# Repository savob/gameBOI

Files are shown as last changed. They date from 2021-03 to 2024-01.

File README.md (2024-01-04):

# gameBOI

My first personal circuit board project which I took on sort of like a hackathon to get done fast so I could show potential employers in the summer of 2019. Designed, ordered, assembled, programmed and debugged in the space of two weeks! Unfotunately I didn't get to show it off much given my limited number of interviews, but still proud of it.

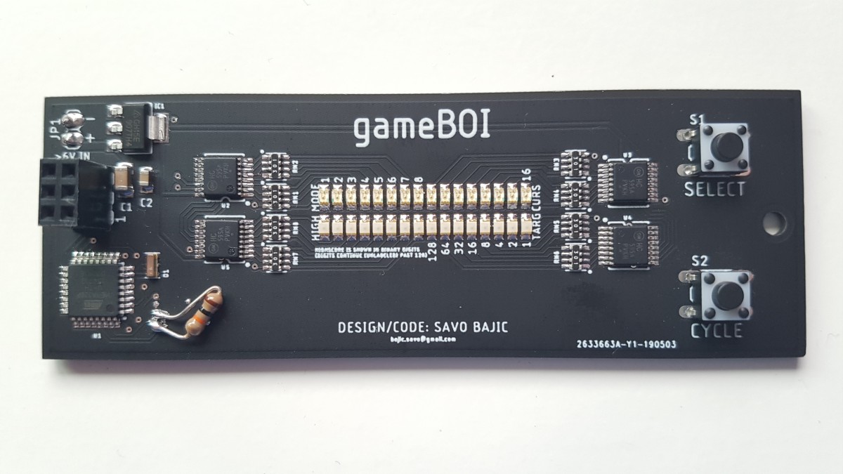
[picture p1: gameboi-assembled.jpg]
Assembled gameBOI board


*I initially forgot to buy one SMD resistor, so had to use a through-hole one.* 

## Hardware

The design is pretty simple looking back, basically the heart of an Arduino Nano with four shift registers daisy-chained to control the LEDs on board. There are two buttons for user input and two rows of 16 LEDs each resulting in the games and UI/UX being pretty simplistic. Power was supplied through a 9V battery that hung off the board going through a linear regulator.

I made two versions of the design, and commited to having the second built and assembled.

## Firmware

By replicating the heart of an Arduino Nano on the board, I could program it just like one through the Arduino IDE. One however was that instead of using a USB-UART interface and the Optiboot bootloader to program the chip, I used the AVR-ISP interface using an Arduino Uno as an ISP.

My code organization was pretty simple and I tried to make it easily scalable. I decided early on that I would make a seperate file for each sort of "stage" the user was in, so `mainmenu` and one for each different game (e.g. `stacker`), as well as one for all the shared functions like updating the screen so they could be maintained easier. *I now realize that what I had accidentally created was a Finite State Machine (FSM), and a project specific library.*

## Software Used

The board was designed in EAGLE (based on release dates, probably v9.4.0). Code was written in the Arduino IDE v1.8.9.

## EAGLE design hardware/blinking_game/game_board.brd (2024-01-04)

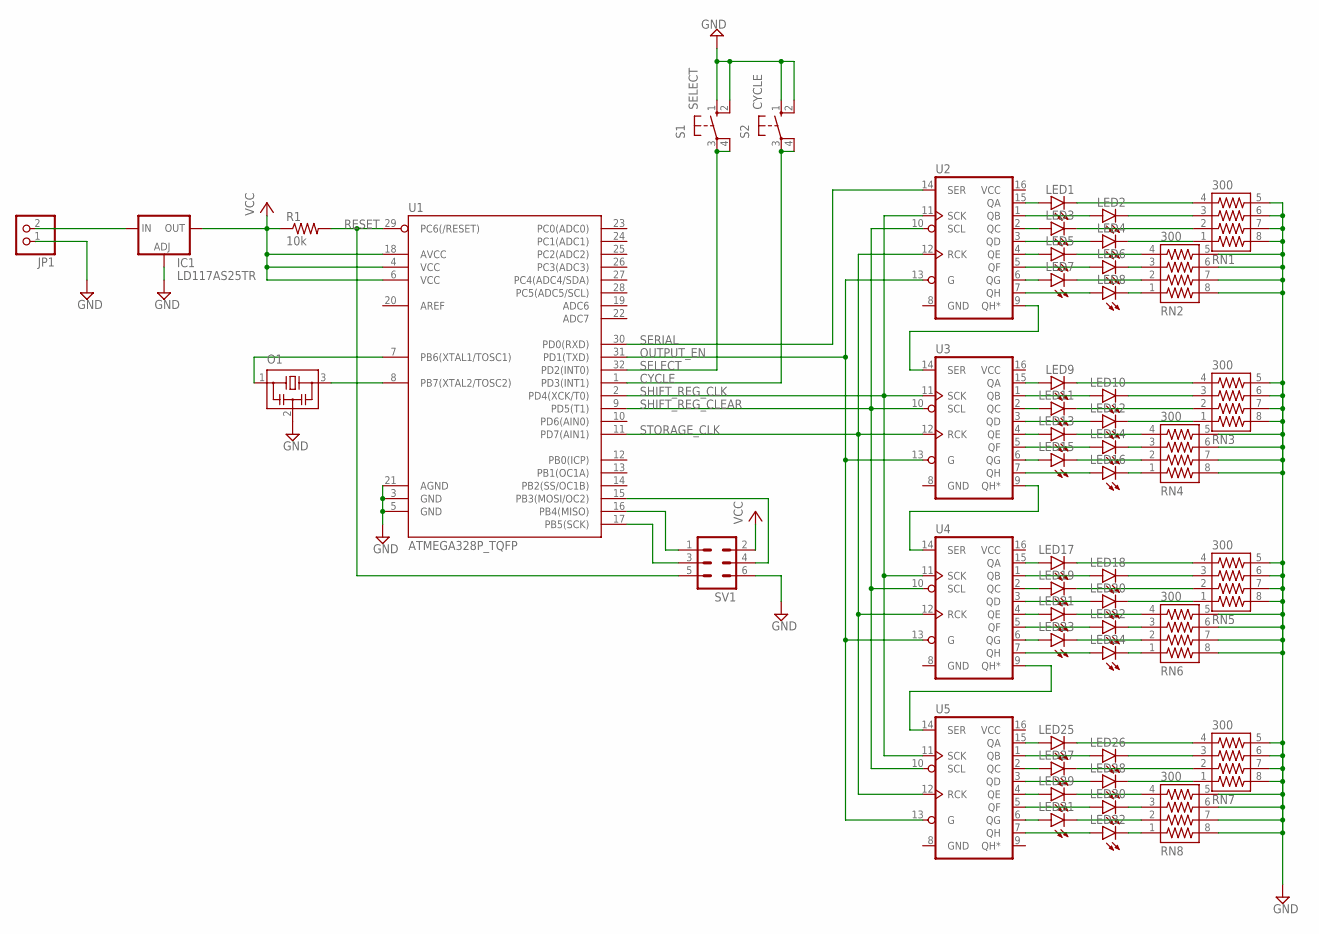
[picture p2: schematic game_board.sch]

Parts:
IC1: LD117AS25TR; SOT223
JP1: PINHD-1X2; 1X02
LED1, LED2, LED3, LED4, LED5, LED6, LED7, LED8, LED9, LED10, LED11, LED12, LED13, LED14, LED15, LED16, LED17, LED18, LED19, LED20, LED21, LED22, LED23, LED24, LED25, LED26, LED27, LED28, LED29, LED30, LED31, LED32: LEDSML0805; SML0805
O1: CSTNE16M0V530000R0; CSTCR6M
R1: 10k; R0603
RN1, RN2, RN3, RN4, RN5, RN6, RN7, RN8: 300; RESCAXS80P320X250X60-8
S1: SELECT; B3F-10XX
S2: CYCLE; B3F-10XX
SV1: MA03-2
U1: ATMEGA328P_TQFP; TQFP32-08
U2, U3, U4, U5: 74595; TSSOP16

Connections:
CYCLE: S2.3, S2.4 (P1), U1.1 (PD3(INT1))
GND: IC1.1 (ADJ), JP1.1, O1.2, RN1.5, RN1.6, RN1.7, RN1.8, RN2.5, RN2.6, RN2.7, RN2.8, RN3.5, RN3.6, RN3.7, RN3.8, RN4.5, RN4.6, RN4.7, RN4.8, RN5.5, RN5.6, RN5.7, RN5.8, RN6.5, RN6.6, RN6.7, RN6.8, RN7.5, RN7.6, RN7.7, RN7.8, RN8.5, RN8.6, RN8.7, RN8.8, S1.1 (S), S1.2 (S1), S2.1 (S), S2.2 (S1), SV1.6, U1.3 (GND), U1.5 (GND), U1.21 (AGND), U2.8 (GND), U3.8 (GND), U4.8 (GND), U5.8 (GND)
MISO: SV1.1, U1.16 (PB4(MISO))
MOSI: SV1.4, U1.15 (PB3(MOSI/OC2))
unnamed: O1.1, U1.7 (PB6(XTAL1/TOSC1))
unnamed: O1.3, U1.8 (PB7(XTAL2/TOSC2))
unnamed: LED17.A, U4.15 (QA)
unnamed: LED18.A, U4.1 (QB)
unnamed: LED17.C, RN5.4
unnamed: LED18.C, RN5.3
unnamed: U3.9 (QH*), U4.14 (SER)
unnamed: U2.9 (QH*), U3.14 (SER)
unnamed: U4.9 (QH*), U5.14 (SER)
unnamed: LED1.A, U2.15 (QA)
unnamed: LED2.A, U2.1 (QB)
unnamed: LED1.C, RN1.4
unnamed: LED2.C, RN1.3
unnamed: LED3.A, U2.2 (QC)
unnamed: LED3.C, RN1.2
unnamed: LED4.C, RN1.1
unnamed: LED4.A, U2.3 (QD)
unnamed: LED5.A, U2.4 (QE)
unnamed: LED6.A, U2.5 (QF)
unnamed: LED5.C, RN2.4
unnamed: LED6.C, RN2.3
unnamed: LED7.C, RN2.2
unnamed: LED7.A, U2.6 (QG)
unnamed: LED8.A, U2.7 (QH)
unnamed: LED8.C, RN2.1
unnamed: LED9.A, U3.15 (QA)
unnamed: LED10.A, U3.1 (QB)
unnamed: LED9.C, RN3.4
unnamed: LED10.C, RN3.3
unnamed: LED11.A, U3.2 (QC)
unnamed: LED11.C, RN3.2
unnamed: LED12.C, RN3.1
unnamed: LED12.A, U3.3 (QD)
unnamed: LED13.A, U3.4 (QE)
unnamed: LED14.A, U3.5 (QF)
unnamed: LED13.C, RN4.4
unnamed: LED14.C, RN4.3
unnamed: LED15.C, RN4.2
unnamed: LED15.A, U3.6 (QG)
unnamed: LED16.A, U3.7 (QH)
unnamed: LED16.C, RN4.1
unnamed: LED19.A, U4.2 (QC)
unnamed: LED19.C, RN5.2
unnamed: LED20.C, RN5.1
unnamed: LED20.A, U4.3 (QD)
unnamed: LED21.A, U4.4 (QE)
unnamed: LED22.A, U4.5 (QF)
unnamed: LED21.C, RN6.4
unnamed: LED22.C, RN6.3
unnamed: LED23.C, RN6.2
unnamed: LED23.A, U4.6 (QG)
unnamed: LED24.A, U4.7 (QH)
unnamed: LED24.C, RN6.1
unnamed: LED25.A, U5.15 (QA)
unnamed: LED26.A, U5.1 (QB)
unnamed: LED25.C, RN7.4
unnamed: LED26.C, RN7.3
unnamed: LED27.A, U5.2 (QC)
unnamed: LED27.C, RN7.2
unnamed: LED28.C, RN7.1
unnamed: LED28.A, U5.3 (QD)
unnamed: LED29.A, U5.4 (QE)
unnamed: LED30.A, U5.5 (QF)
unnamed: LED29.C, RN8.4
unnamed: LED30.C, RN8.3
unnamed: LED31.C, RN8.2
unnamed: LED31.A, U5.6 (QG)
unnamed: LED32.A, U5.7 (QH)
unnamed: LED32.C, RN8.1
unnamed: IC1.3 (IN), JP1.2
OUTPUT_EN: U1.31 (PD1(TXD)), U2.13 (G), U3.13 (G), U4.13 (G), U5.13 (G)
RESET: R1.2, SV1.5, U1.29 (PC6(/RESET))
SCK: SV1.3, U1.17 (PB5(SCK))
SELECT: S1.3, S1.4 (P1), U1.32 (PD2(INT0))
SERIAL: U1.30 (PD0(RXD)), U2.14 (SER)
SHIFT_REG_CLEAR: U1.9 (PD5(T1)), U2.10 (SCL), U3.10 (SCL), U4.10 (SCL), U5.10 (SCL)
SHIFT_REG_CLK: U1.2 (PD4(XCK/T0)), U2.11 (SCK), U3.11 (SCK), U4.11 (SCK), U5.11 (SCK)
STORAGE_CLK: U1.11 (PD7(AIN1)), U2.12 (RCK), U3.12 (RCK), U4.12 (RCK), U5.12 (RCK)
VCC: IC1.4 (OUT), R1.1, SV1.2, U1.4 (VCC), U1.6 (VCC), U1.18 (AVCC), U2.16 (VCC), U3.16 (VCC), U4.16 (VCC), U5.16 (VCC)

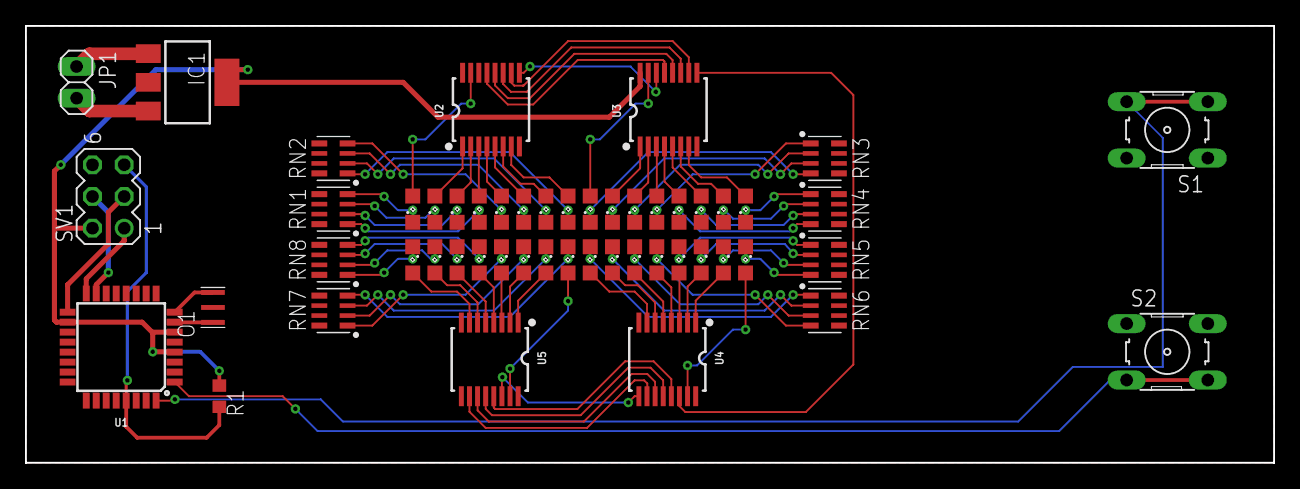
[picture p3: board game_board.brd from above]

Board: 2 copper layers, 100.0 x 35.0 mm, 52 parts (0 on the bottom side), 83 nets.

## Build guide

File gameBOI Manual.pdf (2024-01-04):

# gameBOI Manual

By: Savo Bajic, of course

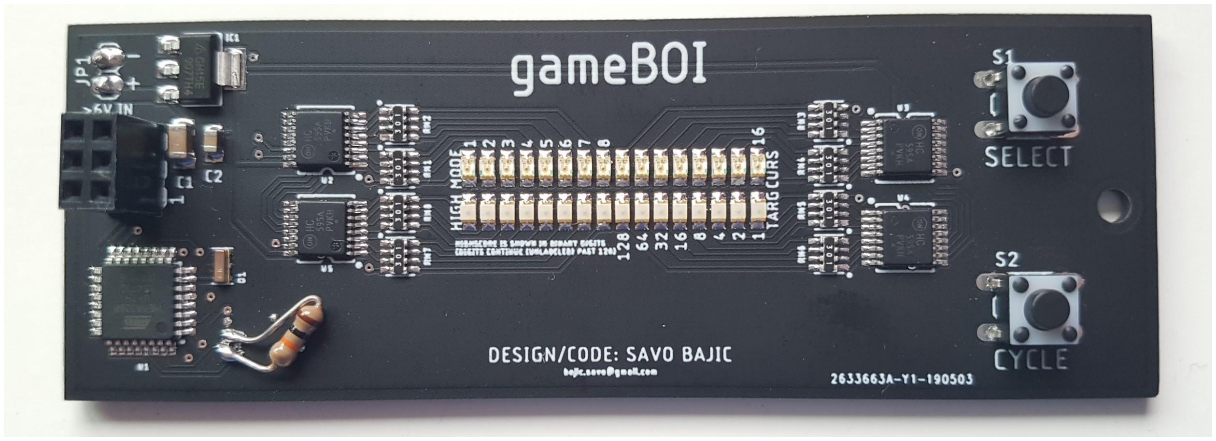
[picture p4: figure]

# General gameBOI overview

Here are some sections outlining the general principles of the gameBOI.

## Hardware

The gameBOI’s hardware is split into sections on the circuit board. Starting with power input in the top left, chances are your gameBOI came with a 9V battery connector pre-soldered there. Any voltage between 6V and 50V can be applied here.

In the middle of the board are two rows of 16 LEDs each which act as the ‘display’ for the unit. The top row is made of green LEDs and is labelled ‘CURS’ and ‘MODE’ at each end. This row is used to display the cursor in games or select game modes in the main menu. The bottom row is made of red LEDs and is labelled ‘TARG’ and ‘HIGH’ at each end. This row is used to show targets in games and display the highscore in binary format when scrolling through game modes in the main menu.

On the right of the gameBOI are the buttons which are used as the only inputs into the system. The top button is labelled ‘SELECT’ and is used to select/start a game mode in the main menu, or interact in a game. The bottom one is labelled ‘CYCLE’ and is used to cycle though the game modes in the main menu, it is not used in any games at this point.

## Operation

When the gameBOI is powered on it will start in the main menu. Here the user can use the ‘CYCLE’ button to cycle through the game modes as indicated in the ‘MODE’ LED row (the LEDs are numbered along the top), as they cycle the bottom row will display the current high score for that mode.

Once the desired mode is reached, the user is to press the ‘SELECT’ button, this will begin the game. The user will then play until they lose, at which point they will be shown their score in the ‘CURS’/’MODE’ row of LEDs and the high score beneath it in the ‘HIGH’/’TARG’ row for comparison. If the user achieved a new highscore the screen will flash and update it. After this the gameBOI will return to the main menu.

### Special Operations

In the main menu there are two other special functions that can be done: resetting the highscores and entering sleep mode.

To reset the highscores (set them all to 0) hold both buttons for over 15 seconds when in the main menu, then release them.

Sleep mode is used to conserve power when the device is not in use without disconnecting power. This will turn off all LEDs and but the microcontroller into a low-power state to minimize power draw. To enter ‘sleep’ mode hold the ‘CYCLE’ button in the main menu for between 5 and 10 seconds before releasing. To return to normal operation, press the ‘CYCLE’ button again.

## Gameplay Mechanics

Although all game modes vary by some degree there are some common mechanics and terms that are shared between them. For example all games make use a cursor that moves along the top (‘CURS’’/MODE’) line of LEDs that is used to aim at targets in the row below, and the user interacts using the ‘SELECT’ button.

### Glossary of terms:

Hit - Pressing ‘SELECT’ when the cursor is over a target. Pressing ‘SELECT’ with the LEDs as they are below would be a ‘hit’.

Miss - Pressing ‘SELECT’ when the cursor is not over a target. Pressing ‘SELECT’ with the cursor in any of the positions shown below would be a ‘miss’.

Pass - The cursor going over a target and not pressing ‘SELECT’ before it moved on. If the cursor is moving from left to right, once the cursor reaches the point below without ‘SELECT’ being pressed, it is a ‘pass’.
-> | -> | ->

# Game Modes

The game list is as follows, they are detailed in their sections: 1 - Escape
2 - Pop can knock off
3 - Skip rope
4 - Stacker
5 - Survival
6 - Swing
7 - Whack a mole

# Escape (1)

The objective is to find holes in the wall to jump through. The cursor scans and you must select any of the openings. If all openings are passed in a round, gameover.

The cursor will speed up and there will be fewer openings as time progresses.

# Pop Can Knockoff (2)

Cursor scans and the goal is to hit targets. Several targets appear at once and they must all be hit before the next round. There is no time limit or penalty for passing targets, but missing will end the game.

Each round will have the same amount of targets, however the cursor speed will gradually increase. There is a point bonus for each complete round finished.

# Skip rope (3)

The user has a constant target at the bottom and the cursor scrolls left to right. The goal is to hit the target to continue and the cursor speeds up every round. This continues until they miss the target or pass it.

# Stacker (4)

Classic stacking game. A block is the foundation and another block scrolls above it. The user tries to place the moving block on top of the other minimizing overhang, any overhang is lost and the newly placed block becomes the new base. The new block will be of the same width as the base.

The user is to try and climb as high as possible, before they place a block that entirely misses and ends the game.

# Survival (5)

Cursor scans edge to edge, the goal is to keep knocking down targets as they pop up and prevent more than a certain amount being present being onscreen at once. There is no time limit nor penalty for misses. However, the cursor will speed up over time to compensate the faster spawn rate of targets

# Swing (6)

The objective of this game is to hit every target as they appear on the bottom row (only one target will be present at any given moment). The cursor will bounce side to side gaining speed with every hit and randomly changing direction after hits.

Should the user pass or miss a target, the game ends.

# Whack a Mole (7)

The user's cursor bounces side to side and they attempt to hit the multiple targets in the bottom row. The goal is to score as many points in the time allowed. Hits add points, and although there is no penalty for passing a target, points are deducted when a shoot is fired without a target.

The cursor speed is constant for the duration of the game.

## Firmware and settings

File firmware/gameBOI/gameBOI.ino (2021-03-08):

/* gameBOI Code

    This is the code for a project of mine, aiming to show off my
    ability to design circuits and code by using an ATmega328P to
    control a series of LEDs using shift registers to make a game
    console that plays a set of one-button games.

    The games also store their highscors in the EEPROM for them
    to make through power-off. There is also the intent to have a
    low power sleep mode so the console doesn't have to have the
    battery constantly connected/disconnected.

    The game list is as follows, they are detailed in their tabs:
       1 - Escape
       2 - Pop can knock off
       3 - Skip rope
       4 - Stacker
       5 - Survival
       6 - Swing
       7 - Whack a mole
*/

#include <EEPROM.h>
#include "LowPower.h"

const byte serialDataPin = 0;     // Data to shift registers
const byte serialClockPin = 4;    // Clock for data (rising edge)
const byte outputEnablePin = 1;   // Enables output of shift registers when LOW
const byte resetDataPin = 5;      // Resets data block of shift registers on LOW - NOT THE OUTPUTS
const byte storageClockPin = 7;   // Moves data from storage to output on rising edge.

const byte selectButton = 2;      // Pin connected to select button (pulled down when pressed)
const byte cycleButton = 3;       // Pin connected to cycle button (pulled down when pressed)

long LEDStatus = 0;               // Stores all LEDs in its bits
// LEDs are counted from 0 in the topleft to 31 going clockwise

// Game related
byte mode = 0;                    // Stores game mode
const byte numberOfModes = 7;     // Stores the number of programmed modes
bool runningGame = false;         // Is a game running or not
unsigned int score = 0;           // Keeps track of score
unsigned int highscores[16];      // Keeps track of high scores
bool firstFrame = true;           // First 'rendered frame' of game? (Used to give people chance to see game starting

const long maxPeriod = 200;       // Maximum / default starting period
const long minPeriod = 50;        // Minimum period between position changes
long period = 50;                 // Stores scrolling period
bool buttonHeld = false;          // Stores whether the select button is being held or not

unsigned long cursorMoveTime = 0; // Next time to move cursor
byte cursorPosition = 0;          // Position of cursor
bool cursorDirection = false;     // Direction of scrolling, right is true
bool cursorBounce = false;        // Does the cursor 'bounce' off edges ('scan')?

void setup() {
  // Output pins
  pinMode(serialDataPin, OUTPUT);
  pinMode(serialClockPin, OUTPUT);
  pinMode(outputEnablePin, OUTPUT);
  pinMode(resetDataPin, OUTPUT);
  pinMode(storageClockPin, OUTPUT);

  // Buttons (they get pulled down on presses
  pinMode(selectButton, INPUT_PULLUP);
  pinMode(cycleButton, INPUT_PULLUP);

  resetLEDs(); // Resets the shift registers
  enableOutput();

  // Reads all highscores from memory to minimize read/write cycles
  for (byte i = 0; i < 16; i++) {
    highscores[i] = EEPROM.get((i * 2), score);

    // After reprogramming over SPI, EEPROM seems to be set to 0xFFFF everywhere.
    // If this is detected, the system will reset highscores
    if (highscores[i] > 10000) {
      resetHighscores();
      break;
    }
  }
}

void loop() {
  if (runningGame) {
    // Run a game
    switch (mode) {
      case 0:
        escape();
        break;
      case 1:
        popCanKnockOff();
        break;
      case 2:
        skipRope();
        break;
      case 3:
        stacker();
        break;
      case 4:
        survival();
        break;
      case 5:
        swing();
        break;
      case 6:
        whackAMole();
        break;
    }
    if (firstFrame) {
      delay(500);               // Let's player process first screen
      randomSeed(millis());     // Randomizes everything
      firstFrame = false;       // No longer first frame
    }
    else delayMicroseconds(500); // Artificial frame rate
  }
  else {
    mainMenu(); // If not playing, it's in the main menu
  }
}

void resetHighscores() {
  // Clears all highscores
  word zero = 0;

  for (int i = 0; i < 16; i++) {
    EEPROM.put(i * 2, zero);
    highscores[i] = zero;
  }
}

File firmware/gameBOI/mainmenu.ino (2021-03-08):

void mainMenu() {
  unsigned long start = millis(); // used to determine the length of button presses
  // Note that the inputs will be low when pressed
  bool cyclePressed = !(digitalRead(cycleButton));
  bool selectPressed = !(digitalRead(selectButton));

  // Display stuff
  resetLEDs();      // Clears old stuff
  LEDOn(mode);      // Shows mode (since the rest of the lights were just cleared)
  showHighscore();  // Shows accompanying highscore and updates display

  // Reset highscores?
  while (!(digitalRead(cycleButton) || digitalRead(selectButton))) {
    // Both pressed
    delay(100);
  }
  if (cyclePressed && selectPressed && ((millis() - start) > 15000)) {
    // Both were pressed for longer than 15 seconds, reset high scores
    resetHighscores();
  }

  // Enter sleep or cycle mode
  while (!(digitalRead(cycleButton)) && digitalRead(selectButton)) {
    // Only cycle pressed
    delay(10);
  }
  if (cyclePressed && !(selectPressed) && ((millis() - start) > 5000) && ((millis() - start) < 10000)) {
    // Cycle pressed for between 5 and 10 seconds
    enterSleep(); // Enter sleep
  }
  else if (cyclePressed && !(selectPressed) && (millis() - start) < 5000) {
    // Short press, increment mode selection
    mode++;
    if (mode == numberOfModes) mode = 0; // Loops back around at the end
  }

  // Select mode?
  while (!(digitalRead(selectButton)) && digitalRead(cycleButton)) {
    // Select pressed
    delay(10);
  }
  if (!(cyclePressed) && selectPressed && ((millis() - start) > 10)) {
    // Select pressed
    selectMode();
  }

  delay(10); // Delay for even when no buttons are pressed
}

void selectMode() {
  runningGame = true; // Time to play...
  score = 0;          // Resets score
  resetLEDs();        // Clears menu
  firstFrame = true;  // Notes it's going to be the first frame of the game
  period = maxPeriod; // Sets default period
  
  // Sets default cursor parameters
  cursorPosition = 0;
  cursorDirection = true;
}

void enterSleep() {
  // Enter lowpower mode
  disableOutput(); // Start by reseting and turning off lights
  attachInterrupt(digitalPinToInterrupt(cycleButton),wakeUp, FALLING);  // Wake up interupt

  // Go to sleep until awoken by cycle button
  LowPower.powerDown(SLEEP_FOREVER, ADC_OFF, BOD_OFF); 
  detachInterrupt(digitalPinToInterrupt(cycleButton)); // Remove interupt
  
  enableOutput(); // Re-enable lights and go back to menu 
}

void wakeUp() {
  // Just exsists to awaken board
}

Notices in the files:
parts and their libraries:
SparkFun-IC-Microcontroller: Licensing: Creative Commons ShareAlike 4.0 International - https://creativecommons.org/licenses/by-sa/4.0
